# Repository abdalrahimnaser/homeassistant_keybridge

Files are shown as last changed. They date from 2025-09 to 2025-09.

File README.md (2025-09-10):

# HASS KeyBridge: Keyboard to Home Assistant MQTT Bridge
<p align="center">
  Untitled Diagram drawio
</p>

This guide will help you set up your KeyBridge (or your esp32 devkit setup as per `/hardware/devkit_setup`) to convert keyboard and macropad commands into Home Assistant MQTT messages for triggering automations.
Note: make sure that your version of esp32 supports USB Host (ESP32S3 tested working).

## License
This project is licensed for non‑commercial use only. Commercial use is prohibited without prior written permission from the copyright holder. See the LICENSE file for full terms.

## ⭐ Show Your Support!

If you find this project useful, please consider giving it a star! It helps increase the project's visibility and is a great way to show your appreciation. Thank you for your support! 🙏

## Prerequisites

Before getting started, ensure your Home Assistant MQTT configuration is properly set up. For detailed instructions, refer to this tutorial: https://www.youtube.com/watch?v=ImBv2mtaRR0&pp=ygUTaG9tZSBhc3Npc3RhbnQgbXF0dA%3D%3D

## Firmware Setup

### 1. Load the Base Project
In ESP-IDF, load the **HID** example project located under **Host** examples.

### 2. Replace Source Files
Replace all files in the `/main` directory (in the esp idf project) with the files from the `/FW` directory in this repository.

### 3. Configure Network Settings
Run the following command to open the configuration menu:
```bash
idf.py menuconfig
```
Navigate to **Example Connection Configuration** and set:
- Your WiFi network SSID
- Your WiFi password

### 4. Configure MQTT Settings
In `firmware_main.c` (line 56), update the following parameters:
- **MQTT Broker URL**: Replace with your Home Assistant IP and MQTT port (keep the `mqtt://` prefix)
- **MQTT Username**: Set your MQTT broker username
- **MQTT Password**: Set your MQTT broker password

### 5. Build and Flash
Build and flash the project to your ESP32, you can do that in one go via the fire icon in the bottom bar of VS Code (must have the ESP IDF extension set up):

## Home Assistant Automation Setup

### Creating MQTT-Triggered Automations

1. Navigate to **Settings** → **Automations & Scenes** → **Create Automation** → **Create New Automation**

2. **Configure the Trigger ("When" section)**:
   - Search for and select the **MQTT** option
   - Set the **Topic** to: `/keybridge/key`
   - Set the **Payload** to your desired key identifier (e.g., `0` for the zero key)

3. **Configure the Action ("Then Do" section)**:
   - Specify the action to perform when the key is pressed
   - Example: Create a persistent notification for testing purposes

## Example Use Case

A basic automation might trigger a persistent notification whenever the `0` key is pressed on your connected keyboard/macropad, demonstrating successful communication between your KeyBridge and Home Assistant.


You can expand this setup to control lights, switches, scenes, or any other Home Assistant entities based on different key combinations from your input device.

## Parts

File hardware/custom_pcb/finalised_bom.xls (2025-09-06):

Comment | Designator | Footprint | JLCPCB Part #
USB_C_Receptacle_USB2.0_16P | J1 | USB-C-SMD_TYPE-C-6PIN-2MD-073 | C2765186
USB_A | J2 | USB-A-SMD_AF180QT1.0 | C404963
LED | D1 | LED0805-R-RD | C2297
ESP32-S3-WROOM-1 | U1 | WIFIM-SMD_ESP32-S3-WROOM-1-N8 | C2913197
1K | R7 | 0402 | C11702
100uF | C3 | 0805 | C141660
100nF | C4,C5 | 0805 | C1711
5.1K | R2,R3 | 0402 | C25905
TLV1117LV-3.3 | U2 | SOT-223-3_TabPin2 | C15578
SW_Push | SW1 | SW-SMD_4P-L6.0-W6.0-P4.50-LS9.2 | C19191552
SW_Slide_DPDT | SW3 | SW-SMD_6P-L7.2-W3.5-P2.50-LS6.0-TL | C2837066
22u | C1,C2 | 0805 | C5674
10K | R1 | 0402 | C25531

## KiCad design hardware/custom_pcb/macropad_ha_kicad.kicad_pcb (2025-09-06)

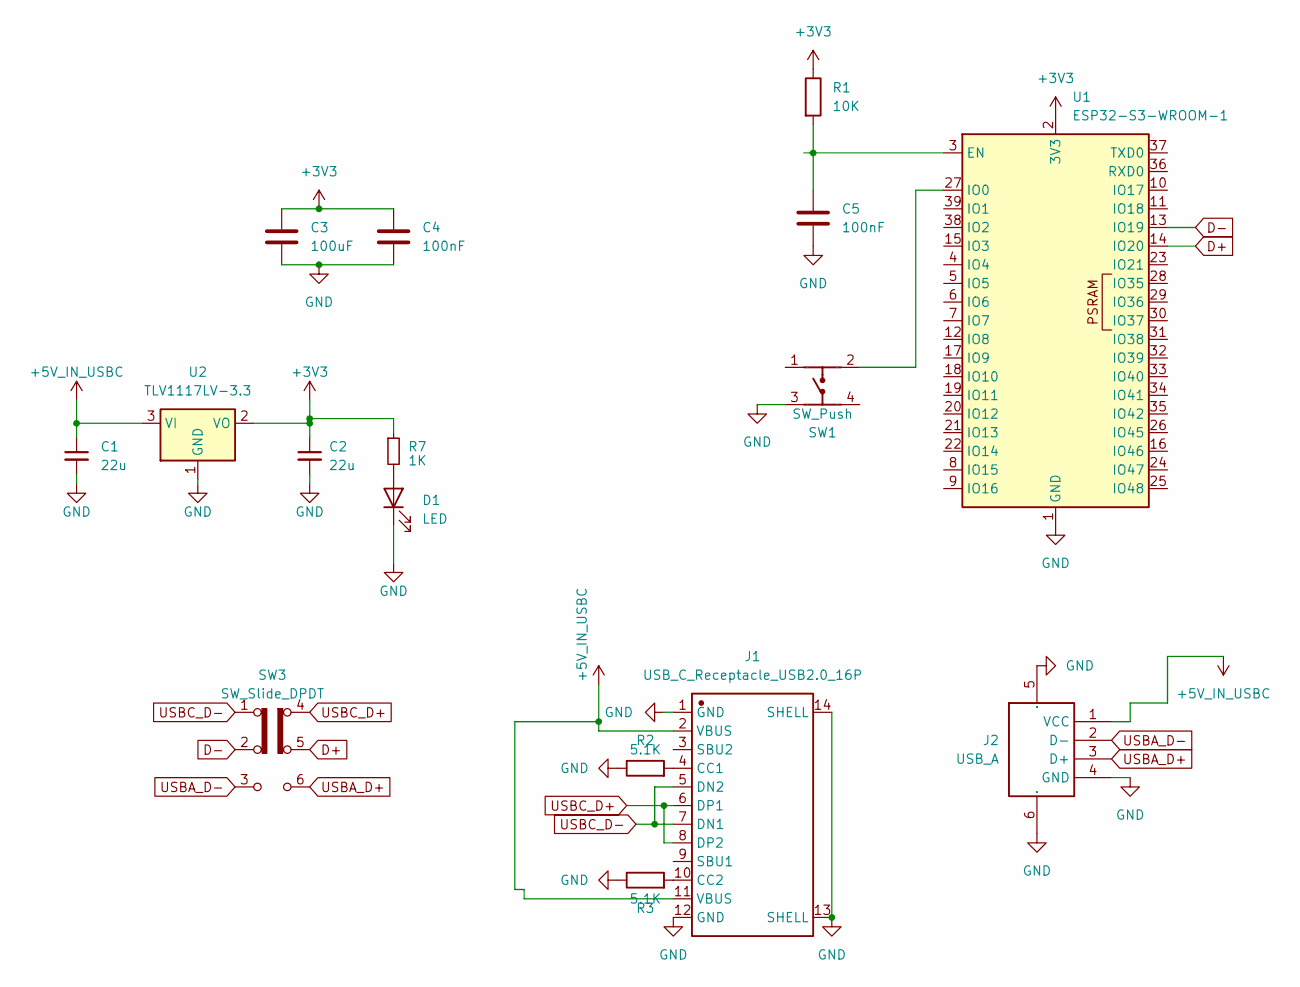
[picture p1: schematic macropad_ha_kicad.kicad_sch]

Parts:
C1, C2: 22u; C_0805_2012Metric_Pad1.18x1.45mm_HandSolder
C3: 100uF; C_0805_2012Metric_Pad1.18x1.45mm_HandSolder
C4, C5: 100nF; C_0805_2012Metric_Pad1.18x1.45mm_HandSolder
D1: LED; LED0805-R-RD
J1: USB_C_Receptacle_USB2.0_16P; USB-C-SMD_TYPE-C-6PIN-2MD-073; Manufacturer Part TYPE-C 16PIN 2MD(073)
J2: USB_A; USB-A-SMD_AF180QT1.0; Manufacturer Part AF180QT1.0
R1: 10K; R_0402_1005Metric_Pad0.72x0.64mm_HandSolder
R2, R3: 5.1K; R_0402_1005Metric_Pad0.72x0.64mm_HandSolder
R7: 1K; R_0402_1005Metric_Pad0.72x0.64mm_HandSolder
SW1: SW_Push; SW-SMD_4P-L6.0-W6.0-P4.50-LS9.2; Manufacturer Part TPS645-5NC60
SW3: SW_Slide_DPDT; SW-SMD_6P-L7.2-W3.5-P2.50-LS6.0-TL
U1: ESP32-S3-WROOM-1; WIFIM-SMD_ESP32-S3-WROOM-1-N8
U2: TLV1117LV-3.3; SOT-223-3_TabPin2

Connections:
+3V3: C2.1, C3.1, C4.1, R1.1, R7.1, U1.2 (3V3), U2.2 (VO)
+5V_IN_USBC: C1.1, J1.2 (VBUS), J1.11 (VBUS), J2.1 (VCC), U2.3 (VI)
D+: SW3.5 (B), U1.14 (IO20)
D-: SW3.2 (B), U1.13 (IO19)
GND: C1.2, C2.2, C3.2, C4.2, C5.2, D1.1 (K), J1.1 (GND), J1.12 (GND), J1.13 (SHELL), J1.14 (SHELL), J2.4 (GND), J2.5 (SH1), J2.6 (SH2), R2.1, R3.1, SW1.3, U1.1 (GND), U1.40 (GND), U1.41 (GND), U2.1 (GND)
unnamed: D1.2 (A), R7.2
unnamed: J1.4 (CC1), R2.2
unnamed: J1.10 (CC2), R3.2
unnamed: C5.1, R1.2, U1.3 (EN)
unnamed: SW1.2, U1.27 (IO0)
USBA_D+: J2.3 (D+), SW3.6 (A)
USBA_D-: J2.2 (D-), SW3.3 (C)
USBC_D+: J1.6 (DP1), J1.8 (DP2), SW3.4 (C)
USBC_D-: J1.5 (DN2), J1.7 (DN1), SW3.1 (A)

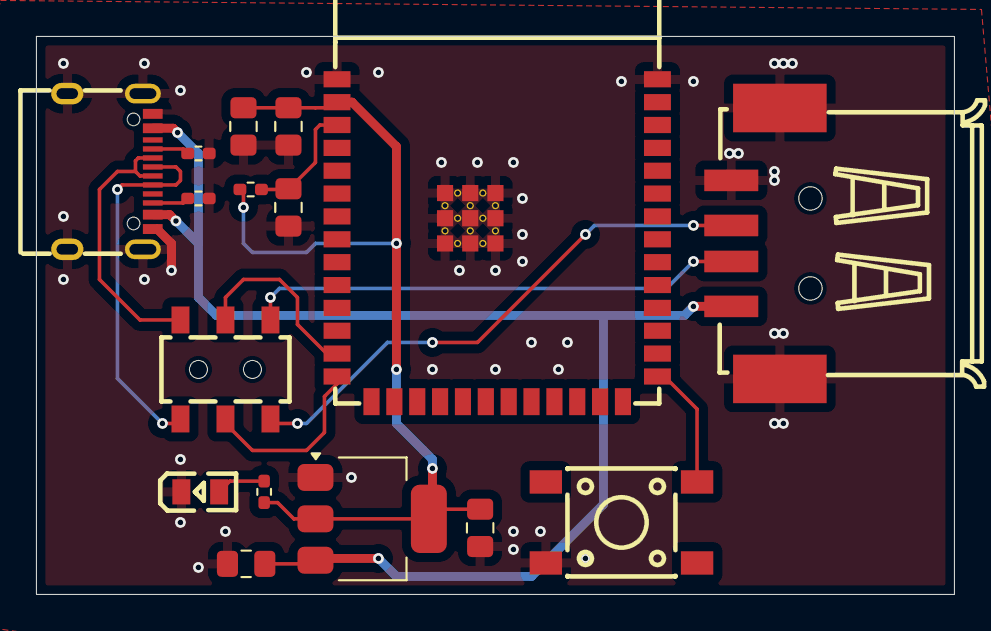
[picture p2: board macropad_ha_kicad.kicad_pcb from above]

Board: 2 copper layers, 51.0 x 31.0 mm, 16 parts (0 on the bottom side), 14 nets.

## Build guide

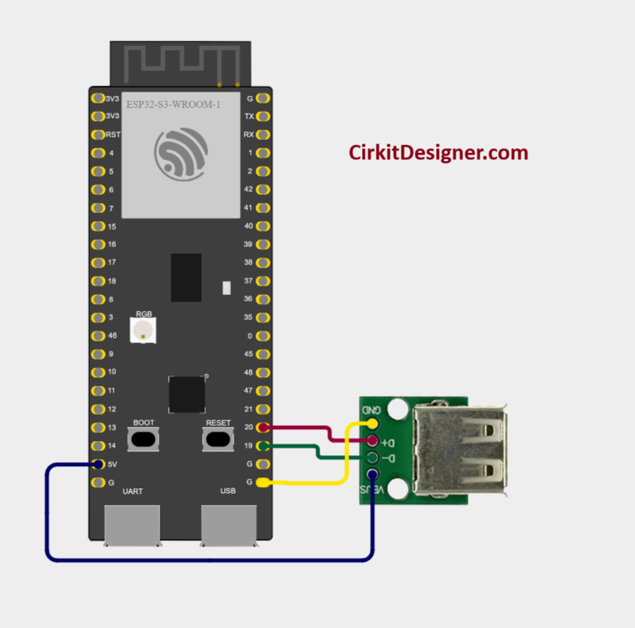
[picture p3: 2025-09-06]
hardware/devkit_setup/sch.png

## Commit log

2025-09-05 Added Custom PCB Files
    [designators.csv, finalised_bom.xls, macropad_ha_kicad.kicad_pcb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]
2025-09-05 Update and rename macropad_ha_kicad.kicad_pcb to hardware/custom_pcb/macropad_ha_kicad.kicad_pcb
    [macropad_ha_kicad.kicad_pcb]
2025-09-05 Update and rename macropad_ha_kicad.kicad_sch to hardware/custom_pcb/macropad_ha_kicad.kicad_sch
    [macropad_ha_kicad.kicad_sch]
2025-09-05 Update and rename macropad_ha_kicad.kicad_sch-bak to hardware/custom_pcb/macropad_ha_kicad.kicad_sch-bak
2025-09-05 Update and rename positions.csv to hardware/custom_pcb/positions.csv
    [positions.csv]
2025-09-05 added schematic for devkit setup
